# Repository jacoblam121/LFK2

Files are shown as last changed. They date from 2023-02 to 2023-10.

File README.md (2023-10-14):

# LFN 65 v2.1.1 (assembly)

65% custom keyboard pcb for mx-type switches

Features:

  Hotswap Sockets
  
  Dual support for ANSI/Tsangan bottom rows
  
  Isolated arrow cluster and delete/home keys





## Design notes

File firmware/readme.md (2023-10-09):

# lfn65

lfn65

*A short description of the keyboard/project*

* Keyboard Maintainer: [jacoblam121](https://github.com/jacoblam121)
* Hardware Supported: *The PCBs, controllers supported*
* Hardware Availability: *Links to where you can find this hardware*

Make example for this keyboard (after setting up your build environment):

    make lfn65:default

Flashing example for this keyboard:

    make lfn65:default:flash

See the [build environment setup](https://docs.qmk.fm/#/getting_started_build_tools) and the [make instructions](https://docs.qmk.fm/#/getting_started_make_guide) for more information. Brand new to QMK? Start with our [Complete Newbs Guide](https://docs.qmk.fm/#/newbs).

## Bootloader

Enter the bootloader in 3 ways:

* **Bootmagic reset**: Hold down the key at (0,0) in the matrix (usually the top left key or Escape) and plug in the keyboard
* **Physical reset button**: Briefly press the button on the back of the PCB - some may have pads you must short instead
* **Keycode in layout**: Press the key mapped to `QK_BOOT` if it is available

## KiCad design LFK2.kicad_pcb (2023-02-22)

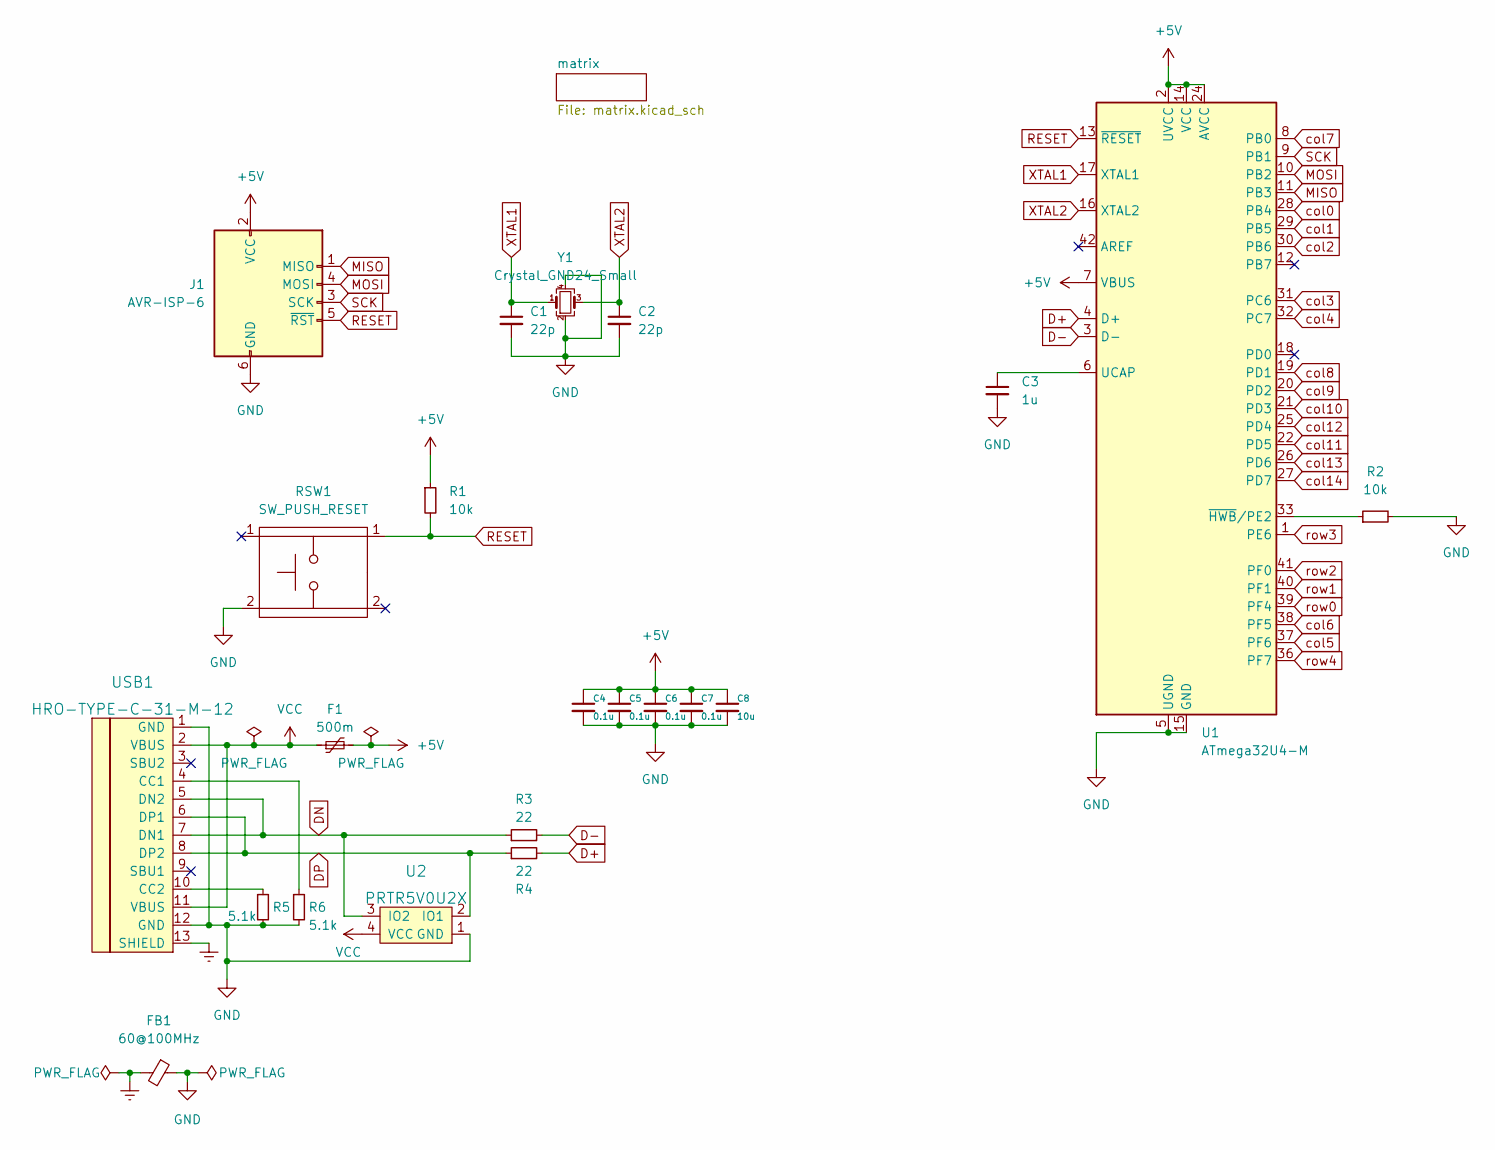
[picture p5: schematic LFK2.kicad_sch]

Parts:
C1, C2: 22p; C_0805_2012Metric
C3: 1u; C_0805_2012Metric
C4, C5, C6, C7: 0.1u; C_0805_2012Metric
C8: 10u; C_0805_2012Metric
F1: 500m; Fuse_1206_3216Metric
FB1: 60@100MHz; L_0805_2012Metric
J1: AVR-ISP-6; Reset_Pretty-Mask
R1, R2: 10k; R_0805_2012Metric
R3, R4: 22; R_0805_2012Metric
R5, R6: 5.1k; R_0805_2012Metric
RSW1: SW_PUSH_RESET; SW_SPST_SKQG_WithStem
U1: ATmega32U4-M; QFN-44-1EP_7x7mm_P0.5mm_EP5.2x5.2mm
U2: PRTR5V0U2X; SOT143B
USB1: HRO-TYPE-C-31-M-12; HRO-TYPE-C-31-M-12-Assembly
Y1: Crystal_GND24_Small; Crystal_SMD_3225-4Pin_3.2x2.5mm

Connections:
+5V: C4.1, C5.1, C6.1, C7.1, C8.1, F1.2, J1.2 (VCC), R1.1, U1.2 (UVCC), U1.7 (VBUS), U1.14 (VCC), U1.24 (AVCC), U1.34 (VCC), U1.44 (AVCC)
D+: R4.2, U1.4 (D+)
D-: R3.2, U1.3 (D-)
DN: R3.1, U2.3 (IO2), USB1.5 (DN2), USB1.7 (DN1)
DP: R4.1, U2.2 (IO1), USB1.6 (DP1), USB1.8 (DP2)
Earth: FB1.2, USB1.13 (SHIELD)
GND: C1.2, C2.2, C3.2, C4.2, C5.2, C6.2, C7.2, C8.2, FB1.1, J1.6 (GND), R2.2, R5.2, R6.2, RSW1.2, U1.5 (UGND), U1.15 (GND), U1.23 (GND), U1.35 (GND), U1.43 (GND), U1.45 (GND), U2.1 (GND), USB1.1 (GND), USB1.12 (GND), Y1.2, Y1.4
MISO: J1.1 (MISO), U1.11 (PB3)
MOSI: J1.4 (MOSI), U1.10 (PB2)
unnamed: C3.1, U1.6 (UCAP)
unnamed: R2.1, U1.33 (~HWB/PE2)
unnamed: R5.1, USB1.10 (CC2)
unnamed: R6.1, USB1.4 (CC1)
RESET: J1.5 (~RST), R1.2, RSW1.1, U1.13 (~RESET)
SCK: J1.3 (SCK), U1.9 (PB1)
VCC: F1.1, U2.4 (VCC), USB1.2 (VBUS), USB1.11 (VBUS)
XTAL1: C1.1, U1.17 (XTAL1), Y1.1
XTAL2: C2.1, U1.16 (XTAL2), Y1.3
col0: U1.28 (PB4); also elsewhere on the board
col1: U1.29 (PB5); also elsewhere on the board
col2: U1.30 (PB6); also elsewhere on the board
col3: U1.31 (PC6); also elsewhere on the board
col4: U1.32 (PC7); also elsewhere on the board
col5: U1.37 (PF6); also elsewhere on the board
col6: U1.38 (PF5); also elsewhere on the board
col7: U1.8 (PB0); also elsewhere on the board
col8: U1.19 (PD1); also elsewhere on the board
col9: U1.20 (PD2); also elsewhere on the board
col10: U1.21 (PD3); also elsewhere on the board
col11: U1.22 (PD5); also elsewhere on the board
col12: U1.25 (PD4); also elsewhere on the board
col13: U1.26 (PD6); also elsewhere on the board
col14: U1.27 (PD7); also elsewhere on the board
row0: U1.39 (PF4); also elsewhere on the board
row1: U1.40 (PF1); also elsewhere on the board
row2: U1.41 (PF0); also elsewhere on the board
row3: U1.1 (PE6); also elsewhere on the board
row4: U1.36 (PF7); also elsewhere on the board

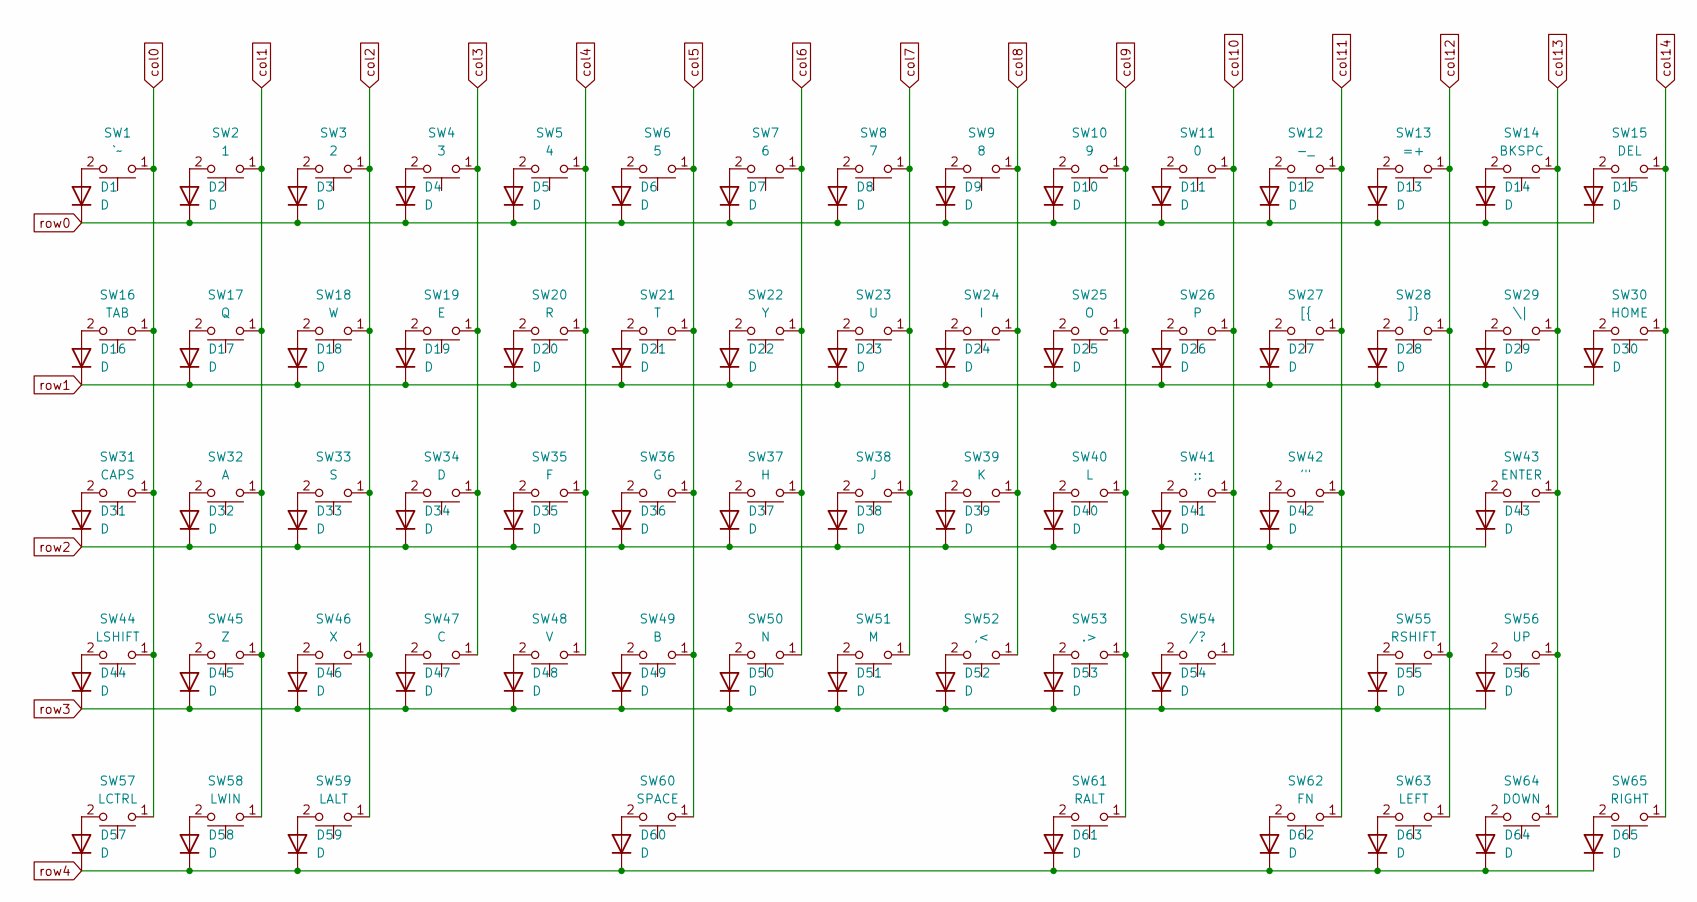
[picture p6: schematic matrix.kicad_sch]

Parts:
D1, D2, D3, D4, D5, D6, D7, D8, D9, D10, D11, D12, D13, D14, D15, D16, D17, D18, D19, D20, D21, D22, D23, D24, D25, D26, D27, D28, D29, D30, D31, D32, D33, D34, D35, D36, D37, D38, D39, D40, D41, D42, D43, D44, D45, D46, D47, D48, D49, D50, D51, D52, D53, D54, D55, D56, D57, D58, D59, D60, D61, D62, D63, D64, D65: D; D_SOD-123
SW1: `~; MXOnly-1U
SW2: 1; MXOnly-1U
SW3: 2; MXOnly-1U
SW4: 3; MXOnly-1U
SW5: 4; MXOnly-1U
SW6: 5; MXOnly-1U
SW7: 6; MXOnly-1U
SW8: 7; MXOnly-1U
SW9: 8; MXOnly-1U
SW10: 9; MXOnly-1U
SW11: 0; MXOnly-1U
SW12: -_; MXOnly-1U
SW13: =+; MXOnly-1U
SW14: BKSPC; MXOnly-2U
SW15: DEL; MXOnly-1U
SW16: TAB; MXOnly-1.5U
SW17: Q; MXOnly-1U
SW18: W; MXOnly-1U
SW19: E; MXOnly-1U
SW20: R; MXOnly-1U
SW21: T; MXOnly-1U
SW22: Y; MXOnly-1U
SW23: U; MXOnly-1U
SW24: I; MXOnly-1U
SW25: O; MXOnly-1U
SW26: P; MXOnly-1U
SW27: [{; MXOnly-1U
SW28: ]}; MXOnly-1U
SW29: \|; MXOnly-1.5U
SW30: HOME; MXOnly-1U
SW31: CAPS; MXOnly-1.75U
SW32: A; MXOnly-1U
SW33: S; MXOnly-1U
SW34: D; MXOnly-1U
SW35: F; MXOnly-1U
SW36: G; MXOnly-1U
SW37: H; MXOnly-1U
SW38: J; MXOnly-1U
SW39: K; MXOnly-1U
SW40: L; MXOnly-1U
SW41: ;:; MXOnly-1U
SW42: '"; MXOnly-1U
SW43: ENTER; MXOnly-2.25U
SW44: LSHIFT; MXOnly-2.25U
SW45: Z; MXOnly-1U
SW46: X; MXOnly-1U
SW47: C; MXOnly-1U
SW48: V; MXOnly-1U
SW49: B; MXOnly-1U
SW50: N; MXOnly-1U
SW51: M; MXOnly-1U
SW52: ,<; MXOnly-1U
SW53: .>; MXOnly-1U
SW54: /?; MXOnly-1U
SW55: RSHIFT; MXOnly-1.75U
SW56: UP; MXOnly-1U
SW57: LCTRL; MXOnly-1.25U
SW58: LWIN; MXOnly-1.25U
SW59: LALT; MXOnly-1.25U
SW60: SPACE; MXOnly-6.25U-ReversedStabilizers
SW61: RALT; MXOnly-1.25U
SW62: FN; MXOnly-1.25U
SW63: LEFT; MXOnly-1U
SW64: DOWN; MXOnly-1U
SW65: RIGHT; MXOnly-1U

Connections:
unnamed: D1.2 (A), SW1.2
unnamed: D2.2 (A), SW2.2
unnamed: D3.2 (A), SW3.2
unnamed: D4.2 (A), SW4.2
unnamed: D5.2 (A), SW5.2
unnamed: D6.2 (A), SW6.2
unnamed: D7.2 (A), SW7.2
unnamed: D8.2 (A), SW8.2
unnamed: D9.2 (A), SW9.2
unnamed: D10.2 (A), SW10.2
unnamed: D11.2 (A), SW11.2
unnamed: D12.2 (A), SW12.2
unnamed: D13.2 (A), SW13.2
unnamed: D14.2 (A), SW14.2
unnamed: D15.2 (A), SW15.2
unnamed: D16.2 (A), SW16.2
unnamed: D17.2 (A), SW17.2
unnamed: D18.2 (A), SW18.2
unnamed: D19.2 (A), SW19.2
unnamed: D20.2 (A), SW20.2
unnamed: D21.2 (A), SW21.2
unnamed: D22.2 (A), SW22.2
unnamed: D23.2 (A), SW23.2
unnamed: D24.2 (A), SW24.2
unnamed: D25.2 (A), SW25.2
unnamed: D26.2 (A), SW26.2
unnamed: D27.2 (A), SW27.2
unnamed: D28.2 (A), SW28.2
unnamed: D29.2 (A), SW29.2
unnamed: D30.2 (A), SW30.2
unnamed: D31.2 (A), SW31.2
unnamed: D32.2 (A), SW32.2
unnamed: D33.2 (A), SW33.2
unnamed: D34.2 (A), SW34.2
unnamed: D35.2 (A), SW35.2
unnamed: D36.2 (A), SW36.2
unnamed: D37.2 (A), SW37.2
unnamed: D38.2 (A), SW38.2
unnamed: D39.2 (A), SW39.2
unnamed: D40.2 (A), SW40.2
unnamed: D41.2 (A), SW41.2
unnamed: D42.2 (A), SW42.2
unnamed: D43.2 (A), SW43.2
unnamed: D44.2 (A), SW44.2
unnamed: D45.2 (A), SW45.2
unnamed: D46.2 (A), SW46.2
unnamed: D47.2 (A), SW47.2
unnamed: D48.2 (A), SW48.2
unnamed: D49.2 (A), SW49.2
unnamed: D50.2 (A), SW50.2
unnamed: D51.2 (A), SW51.2
unnamed: D52.2 (A), SW52.2
unnamed: D53.2 (A), SW53.2
unnamed: D54.2 (A), SW54.2
unnamed: D55.2 (A), SW55.2
unnamed: D56.2 (A), SW56.2
unnamed: D57.2 (A), SW57.2
unnamed: D58.2 (A), SW58.2
unnamed: D59.2 (A), SW59.2
unnamed: D60.2 (A), SW60.2
unnamed: D61.2 (A), SW61.2
unnamed: D62.2 (A), SW62.2
unnamed: D63.2 (A), SW63.2
unnamed: D64.2 (A), SW64.2
unnamed: D65.2 (A), SW65.2
col0: SW1.1, SW16.1, SW31.1, SW44.1, SW57.1; also elsewhere on the board
col1: SW2.1, SW17.1, SW32.1, SW45.1, SW58.1; also elsewhere on the board
col2: SW3.1, SW18.1, SW33.1, SW46.1, SW59.1; also elsewhere on the board
col3: SW4.1, SW19.1, SW34.1, SW47.1; also elsewhere on the board
col4: SW5.1, SW20.1, SW35.1, SW48.1; also elsewhere on the board
col5: SW6.1, SW21.1, SW36.1, SW49.1, SW60.1; also elsewhere on the board
col6: SW7.1, SW22.1, SW37.1, SW50.1; also elsewhere on the board
col7: SW8.1, SW23.1, SW38.1, SW51.1; also elsewhere on the board
col8: SW9.1, SW24.1, SW39.1, SW52.1; also elsewhere on the board
col9: SW10.1, SW25.1, SW40.1, SW53.1, SW61.1; also elsewhere on the board
col10: SW11.1, SW26.1, SW41.1, SW54.1; also elsewhere on the board
col11: SW12.1, SW27.1, SW42.1, SW62.1; also elsewhere on the board
col12: SW13.1, SW28.1, SW55.1, SW63.1; also elsewhere on the board
col13: SW14.1, SW29.1, SW43.1, SW56.1, SW64.1; also elsewhere on the board
col14: SW15.1, SW30.1, SW65.1; also elsewhere on the board
row0: D1.1 (K), D2.1 (K), D3.1 (K), D4.1 (K), D5.1 (K), D6.1 (K), D7.1 (K), D8.1 (K), D9.1 (K), D10.1 (K), D11.1 (K), D12.1 (K), D13.1 (K), D14.1 (K), D15.1 (K); also elsewhere on the board
row1: D16.1 (K), D17.1 (K), D18.1 (K), D19.1 (K), D20.1 (K), D21.1 (K), D22.1 (K), D23.1 (K), D24.1 (K), D25.1 (K), D26.1 (K), D27.1 (K), D28.1 (K), D29.1 (K), D30.1 (K); also elsewhere on the board
row2: D31.1 (K), D32.1 (K), D33.1 (K), D34.1 (K), D35.1 (K), D36.1 (K), D37.1 (K), D38.1 (K), D39.1 (K), D40.1 (K), D41.1 (K), D42.1 (K), D43.1 (K); also elsewhere on the board
row3: D44.1 (K), D45.1 (K), D46.1 (K), D47.1 (K), D48.1 (K), D49.1 (K), D50.1 (K), D51.1 (K), D52.1 (K), D53.1 (K), D54.1 (K), D55.1 (K), D56.1 (K); also elsewhere on the board
row4: D57.1 (K), D58.1 (K), D59.1 (K), D60.1 (K), D61.1 (K), D62.1 (K), D63.1 (K), D64.1 (K), D65.1 (K); also elsewhere on the board

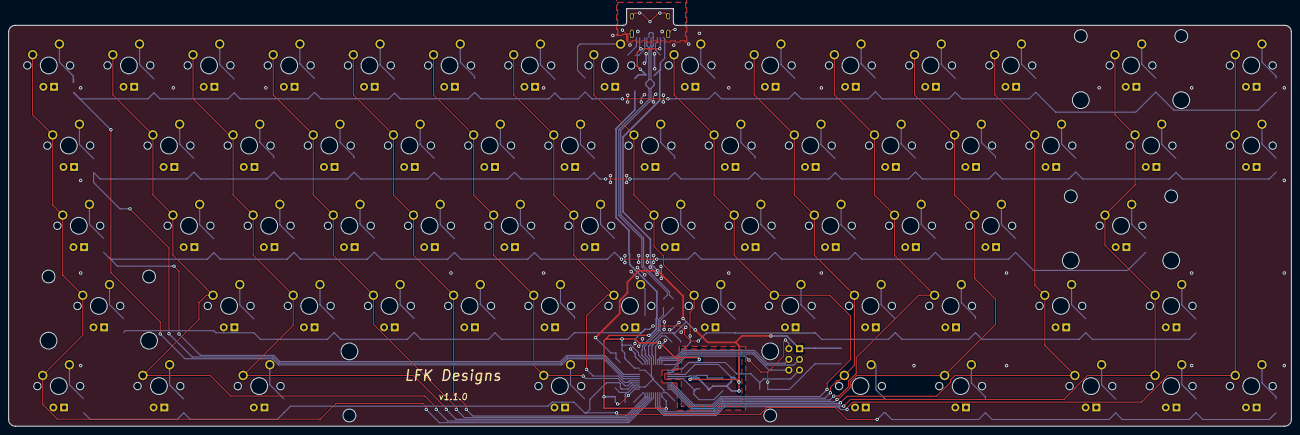
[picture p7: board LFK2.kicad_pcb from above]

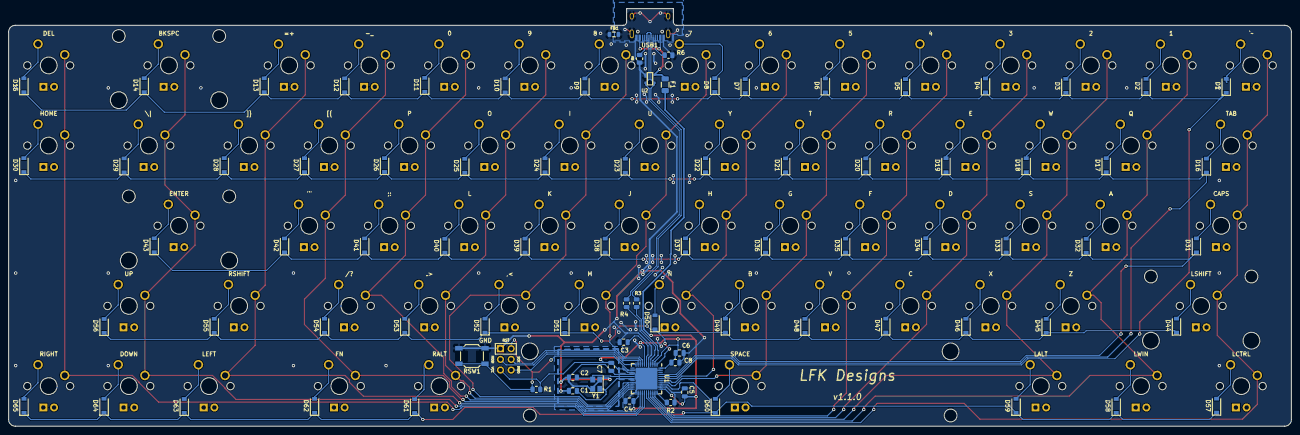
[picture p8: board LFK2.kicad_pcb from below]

Board: 2 copper layers, 304.8 x 99.2 mm, 152 parts (87 on the bottom side), 103 nets.

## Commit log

2023-05-18 v2.0.1
    Left more room for traces (screws)
    [LFK2.kicad_sch]
2023-05-23 v2.1.1
    Tsangan WK and Small Fixes
    [LFK2.kicad_sch, matrix.kicad_sch]
2023-10-09 Uploaded gerber and pcb files.
    Gerber files include drill maps.
    Pcb files include footprint designations and placement coordinates.
    [LFK2.csv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]
2023-10-09 Uploaded gerber files
    [LFK2-B_Cu.gbl, LFK2-B_Mask.gbs, LFK2-B_Paste.gbp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]
2023-10-09 Uploaded bom/pick and place files
    [LFK2.csv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]
